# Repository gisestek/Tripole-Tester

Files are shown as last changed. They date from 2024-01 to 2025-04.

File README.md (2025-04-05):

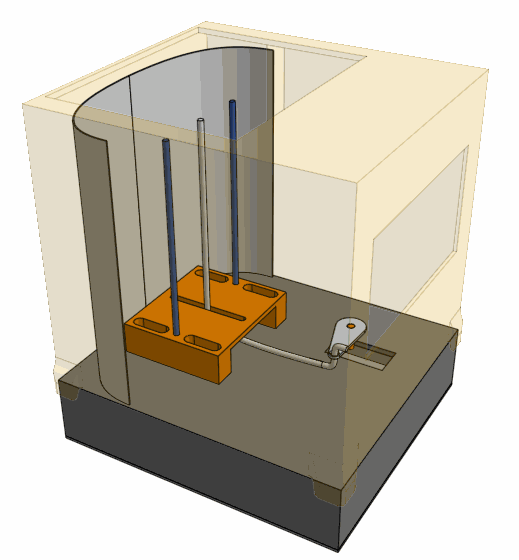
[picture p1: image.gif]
Laite


# Ihmisen syvyysnäön testauslaite

Testi perustuu klassiseen Howard-Dolman -testin periaatteeseen. Laitteessa on kolme pystysuoraa tolppaa (tai sauvaa) rivissä. Koehenkilö katsoo tolppia tietytä etäisyydeltä. Keskimmäistä tolppaa voidaan liikuttaa servo-ohjatusti eteen- tai taaksepäin suhteessa reunimmaisiin tolppiin. Koehenkilön tehtävä on arvioida, onko keskimmäinen tolppa lähempänä vai kauempana kuin reunimmaiset. Etäisyysero reunimmaisiin tolppiin pienenee testin edetessä, ja kun testattava on tehny kolme virhettä, on löydetty stereoerottelykyvyn raja.

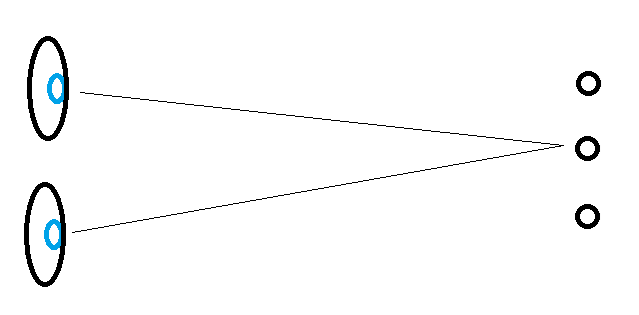
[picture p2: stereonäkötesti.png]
Testin periaatekuva


Testilaite muodostaa WiFI-tukiaseman, johon liitytään kahdella laitteella: 1. Testaajan laite sekä 2. Testattavan pääte.
* Testaajan laitteessa syötetään testihenkilön nimi ja aloitetaan uusi testi, voi seurata testin etenemistä sekä kerätään tulokset. Tulokset voi ladata myös .csv-tiedostona
* Testattavan päätteessä (kännykkä on hyvä) on painikkeet, joilla arvio keskitolpan etäisyydestä tehdään (Lähellä/Kaukana)

## Käyttö:

Kun virrat on päällä, molemmilla laitteilla liitytään WiFiin "Stereovisiontest" (salasana: 12345678)

Testaaja menee selaimella osoitteeseen http://192.168.4.1/admin

Testattava menee selaimella osoitteeseen http://192.168.4.1/

Kansion admin.html ja subject.html ovat emulaattoreita, joilla voi kokeilla interaktiivisesti millaiset GUI:t ovat.

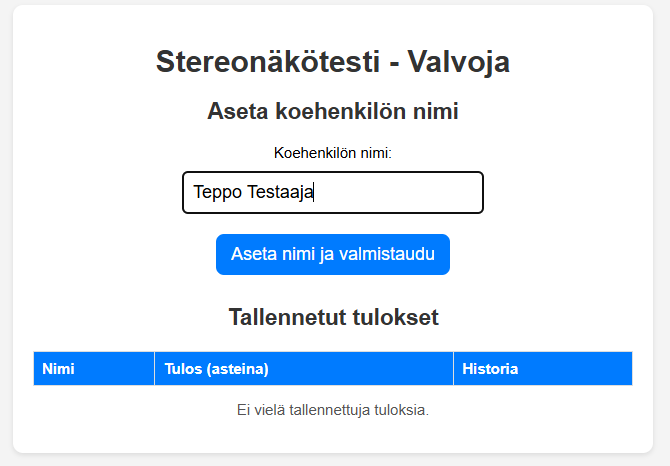
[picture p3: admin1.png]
Admin1

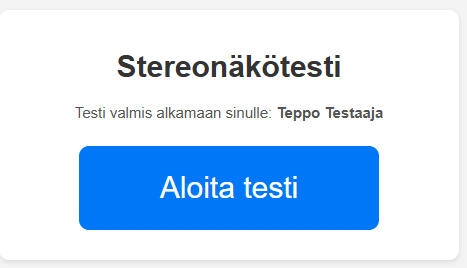
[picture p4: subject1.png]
subject1

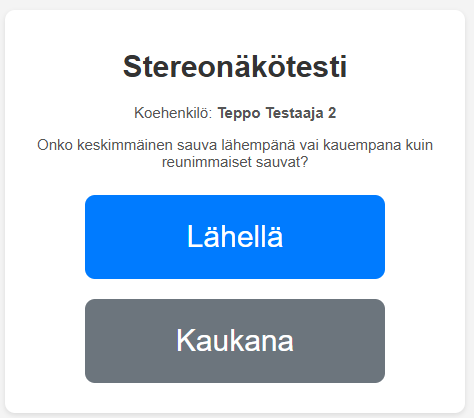
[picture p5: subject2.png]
subject2

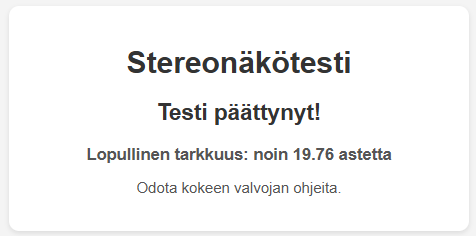
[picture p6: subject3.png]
subject3

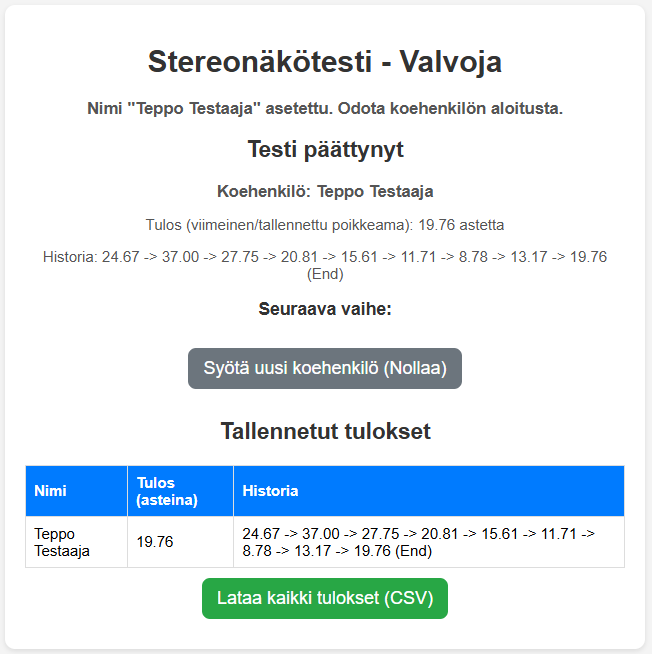
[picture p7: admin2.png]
Admin2


## Laitteisto:

* ESP32
* 9g servo
* Teräslanka (esim TIG-hitsauslankaa)
* 3D-tulostetut osat 
* [Onshape mallit](https://cad.onshape.com/documents/015ba60578bb0acbbb4cbba4/w/e4783b3f15ab7f564ce377d3/e/8b8e0c89aea4ec2eb4cf4481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)

# Stereonäkötestilaitteen katseluetäisyys

Jotta voidaan mitata stereonäön tarkkuutta noin 10 kaarisekunnin tasolle asti:
 
**Laitteiston parametrit:**
* Tolppien välinen sivuttaisetäisyys: n. 10 mm
* Keskimmäisen tolpan liikerata (syvyyssuunnassa): n. 18 mm ( ±9 mm keskikohdasta)

## Laskennan Perusteet

Stereonäön tarkkuus (η) kuvaa pienintä syvyyseroa, jonka henkilö pystyy havaitsemaan kahden eri etäisyydellä olevan kohteen välillä. Se ilmaistaan usein kulmayksiköissä (kaarisekunteina) ja riippuu silmien välisestä etäisyydestä (IPD), kohteiden välisestä fyysisestä syvyyserosta (Δd) ja katseluetäisyydestä (D).

**Kaava:**
Stereotarkkuus radiaaneina approksimoidaan kaavalla:

`η (rad) ≈ (IPD * Δd) / D²`

Missä:
* `η`: Stereotarkkuus radiaaneina
* `IPD`: Silmien välinen etäisyys (Interpupillary distance) metreinä
* `Δd`: Kohteiden välinen syvyysero metreinä
* `D`: Katseluetäisyys metreinä

## Parametrit ja Laskenta

Tavoitteena on laskea etäisyys `D`, jolla laitteen suurin mahdollinen syvyysero `Δd_max` tuottaa juuri 10 kaarisekunnin parallaksieron.

1.  **Tavoiteltu stereotarkkuus (η):**
    * `η = 10 kaarisekuntia`
    * Muunnos radiaaneiksi: `10" = (10 / 3600) * (π / 180) rad ≈ 4.848 * 10⁻⁵ rad`

2.  **Silmien välinen etäisyys (IPD):**
    * Käytetään yleistä keskiarvoa: `IPD ≈ 65 mm = 0.065 m`
    * *Huom: Tämä on oletus, todellinen IPD vaihtelee.*

3.  **Suurin syvyysero (Δd_max):**
    * Laitteen liikerata on 18 mm, joten suurin siirtymä keskikohdasta on puolet siitä.
    * `Δd_max = 18 mm / 2 = 9 mm = 0.009 m`

4.  **Katseluetäisyyden (D) ratkaiseminen:**
    * Muokataan kaavaa: `D² ≈ (IPD * Δd) / η`
    * `D ≈ √[ (IPD * Δd_max) / η ]`
    * Sijoitetaan arvot:
        `D ≈ √[ (0.065 m * 0.009 m) / (4.848 * 10⁻⁵ rad) ]`
        `D ≈ √[ 0.000585 m² / 4.848 * 10⁻⁵ ]`
        `D ≈ √[ 12.067 m² ]`
        `D ≈ 3.47 m`

Tällöin testilaitteen suositeltu katseluetäisyys on noin **3,5 metriä**.

Tällä etäisyydellä laitteen suurin fyysinen syvyyssiirtymä (9 mm) vastaa noin 10 kaarisekunnin stereotarkkuutta (olettaen 65 mm IPD). Tämä mahdollistaa testauksen tavoitellulla tarkkuustasolla laitteen mekaanisten rajoitusten puitteissa. Testiprotokollassa pyritään löytämään pienin havaittava siirtymä, mutta tämä laskettu etäisyys varmistaa, että 10 kaarisekunnin taso on saavutettavissa. Jos teet erikokoisen laitteen, etäisyys on toki eri.

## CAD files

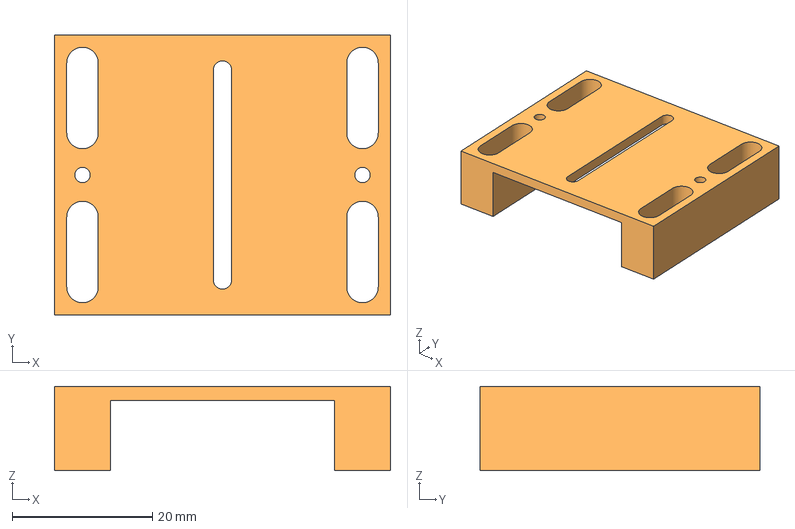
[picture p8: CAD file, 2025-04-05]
3D-mallit/stereonäkömittari - ohjain.3mf
48.0 x 40.0 x 12.0 mm

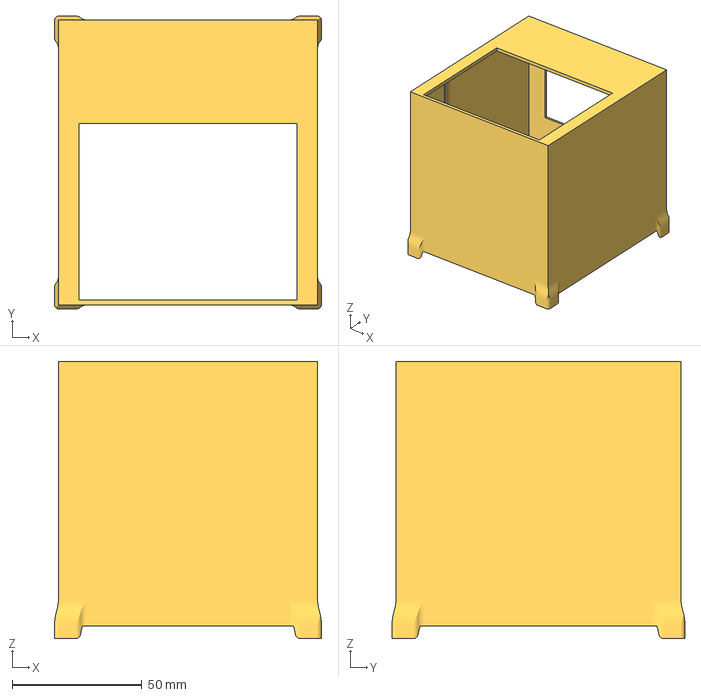
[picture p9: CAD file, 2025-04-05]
3D-mallit/stereonäkömittari - laatikko.3mf
103.0 x 113.0 x 107.0 mm

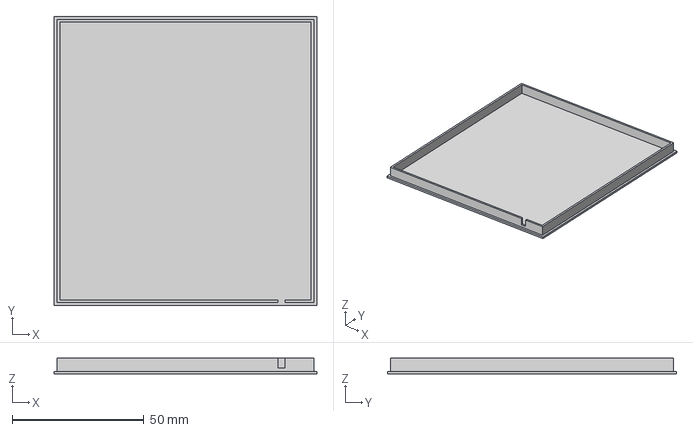
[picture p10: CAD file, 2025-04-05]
3D-mallit/stereonäkömittari - Pohja.3mf
100.0 x 110.0 x 6.00 mm

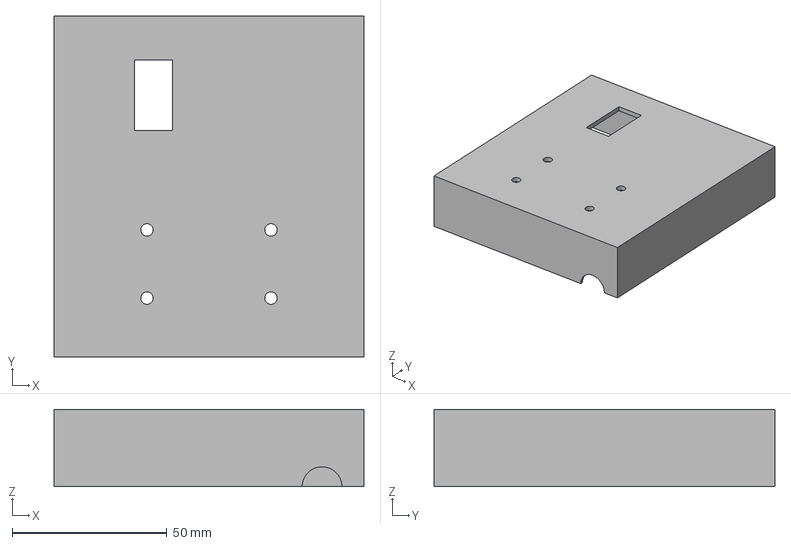
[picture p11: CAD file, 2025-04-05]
3D-mallit/stereonäkömittari - Alusta.3mf
100.0 x 110.0 x 25.0 mm

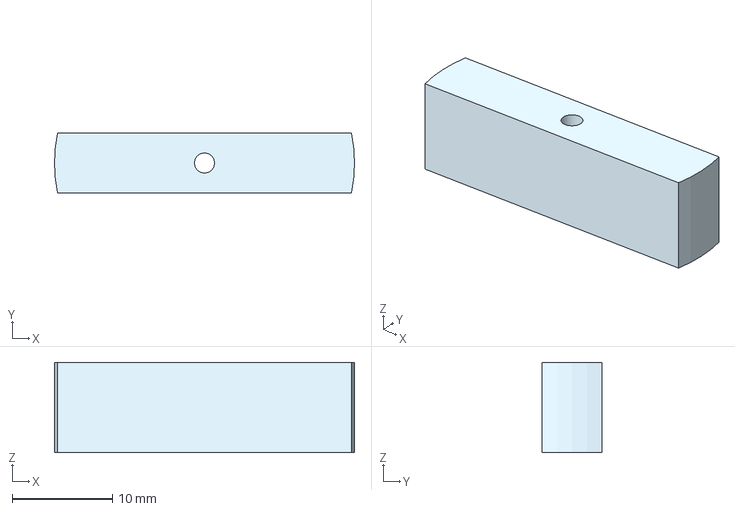
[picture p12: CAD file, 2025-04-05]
3D-mallit/stereonäkömittari - vakain.3mf
30.0 x 6.00 x 9.00 mm

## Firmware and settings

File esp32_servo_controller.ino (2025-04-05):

#include <WiFi.h>
#include <WebServer.h>
#include <ESP32Servo.h>
#include <vector>   // Added for storing results
#include <string>   // Added for string manipulation (optional but good practice)
#include <sstream>  // Added for CSV generation

// WiFi Access Point credentials
const char *ssid = "Stereovisiontest";
const char *password = "12345678"; // Käytä vahvempaa salasanaa tarvittaessa

// Web server on port 80
WebServer server(80);

// Servo setup
Servo servo;
const int servoPin = 13;

// --- Test Variables ---
int centerPosition = 90;  // Servon keskikohta (astetta)
double deflection = 30.0; // Alkupoikkeama (astetta) - Käytetään double tarkkuutta varten
int wrongGuesses = 0;
const int maxWrongGuesses = 3;
bool gameOver = false;
bool gameStarted = false;
int currentPosition; // Servon nykyinen asento (astetta)
const double maxDeflection = 37.0; // Maksimipoikkeama keskikohdasta (astetta)
String deflectionHistory = "";
String currentSubjectName = ""; // Nykyisen koehenkilön nimi

// --- Data Storage ---
struct ResultData {
  String name;
  double finalDeflection;
  String history;
  // Voit lisätä aikaleiman tarvittaessa: unsigned long timestamp;
};
std::vector<ResultData> allResults; // Vektori kaikkien testien tuloksille

// --- HTML & CSS ---
const char* HTML_HEADER = "<!DOCTYPE html><html><head>"
                          "<meta charset='UTF-8'>"
                          "<meta name='viewport' content='width=device-width, initial-scale=1.0'>"
                          "<title>Stereonäkötesti</title>"
                          "<style>"
                          "body { font-family: Arial, sans-serif; text-align: center; margin: 0; padding: 20px; background-color: #f4f4f4; }"
                          "h1, h2, h3 { color: #333; }"
                          "p { color: #555; }"
                          ".container { max-width: 600px; margin: auto; background-color: #fff; padding: 20px; border-radius: 10px; box-shadow: 0 2px 5px rgba(0,0,0,0.1); }"
                          "button, input[type=submit] { font-size: 24px; padding: 15px 20px; margin: 10px 5px; width: calc(80% - 10px); max-width: 300px; border: none; border-radius: 10px; background-color: #007BFF; color: white; cursor: pointer; transition: background-color 0.3s ease; }"
                          "button:hover, input[type=submit]:hover { background-color: #0056b3; }"
                          "button.large-btn { width: calc(90% - 10px); padding: 25px 20px; font-size: 30px; }" // Larger buttons for subject
                          "button.secondary-btn { background-color: #6c757d; }"
                          "button.secondary-btn:hover { background-color: #5a6268; }"
                          "button.download-btn { background-color: #28a745; }"
                          "button.download-btn:hover { background-color: #218838; }"
                          "input[type=text] { font-size: 20px; padding: 10px; margin: 10px 0; width: calc(80% - 22px); max-width: 280px; border: 1px solid #ccc; border-radius: 5px; }"
                          "table { width: 100%; margin-top: 20px; border-collapse: collapse; }"
                          "th, td { border: 1px solid #ddd; padding: 8px; text-align: left; }"
                          "th { background-color: #007BFF; color: white; }"
                          "tr:nth-child(even) { background-color: #f2f2f2; }"
                          ".status { font-weight: bold; margin: 15px 0; font-size: 1.1em; }"
                          ".error { color: red; font-weight: bold; }"
                          "</style></head><body><div class='container'>";

const char* HTML_FOOTER = "</div></body></html>";


// --- Function Declarations ---
void handleRoot();
void handleAdmin();
void handleSetName();
void handleStartGame();
void handleGuess();
void handleDownload();
void resetGame(bool keepName = false);
void setServo();
void setResetMovement();
String getAdminPageContent(String extraMessage = "");
String getSubjectPageContent();
String generateCSV();

// --- Setup ---
void setup() {
    Serial.begin(115200);
    Serial.println("Starting Stereovision Test Server...");

    // Servo setup
    servo.attach(servoPin);
    servo.write(centerPosition); // Aseta servo keskelle alussa
    delay(500); // Pieni viive servon asettumiselle

    // WiFi setup
    WiFi.softAP(ssid, password);
    Serial.print("Access Point SSID: ");
    Serial.println(ssid);
    Serial.print("IP Address: ");
    Serial.println(WiFi.softAPIP());

    // Web server routes
    server.on("/", HTTP_GET, handleRoot);              // Koehenkilön sivu
    server.on("/admin", HTTP_GET, handleAdmin);        // Valvojan sivu
    server.on("/setname", HTTP_POST, handleSetName);   // Nimen asetus (valvoja)
    server.on("/start", HTTP_GET, handleStartGame);    // Testin aloitus (koehenkilö)
    server.on("/guess", HTTP_GET, handleGuess);        // Arvauksen käsittely (koehenkilö)
    server.on("/download", HTTP_GET, handleDownload);  // Tulosten lataus (valvoja)

    server.begin();
    Serial.println("HTTP server started");
    resetGame(true); // Nollaa pelitila, mutta ei välttämättä nimeä alussa
}

// --- Main Loop ---
void loop() {
    server.handleClient();
}

// --- Game Logic ---

// Nollaa testin tila
void resetGame(bool keepName /*= false*/) {
    Serial.println("Resetting game state...");
    deflection = 30.0; // Palauta alkupoikkeama
    wrongGuesses = 0;
    gameOver = false;
    gameStarted = false;
    deflectionHistory = "";
    if (!keepName) {
        currentSubjectName = ""; // Nollaa nimi vain jos keepName on false
        Serial.println("Current subject name cleared.");
    }
    servo.write(centerPosition); // Servo keskelle
    Serial.println("Game reset complete.");
}

// Aloittaa testin (kun koehenkilö painaa Aloita)
void handleStartGame() {
    if (currentSubjectName == "") {
        // Estä aloitus jos nimeä ei ole asetettu
        server.send(200, "text/html", String(HTML_HEADER) + "<h1>Odota</h1><p class='error'>Kokeen valvojan täytyy asettaa nimesi ensin /admin-sivulla.</p>" + HTML_FOOTER);
        return;
    }
    if (!gameStarted) {
        Serial.println("Starting game for: " + currentSubjectName);
        gameStarted = true;
        gameOver = false;
        wrongGuesses = 0;
        deflection = 30.0; // Varmista alkupoikkeama
        deflectionHistory = "";
        setResetMovement(); // Suorita nollausliike
        setServo();         // Aseta ensimmäinen testiasento
        Serial.println("Game started. Initial deflection: " + String(deflection));
    }
    // Ohjaa käyttäjä takaisin pääsivulle (joka näyttää nyt arvauspainikkeet)
    server.sendHeader("Location", "/");
    server.send(303);
}

// Siirtää servon kauas eteen/taakse ennen uutta asentoa
void setResetMovement() {
    int resetPosition = centerPosition + (random(2) ? maxDeflection : -maxDeflection);
    Serial.println("Performing reset movement to: " + String(resetPosition));
    servo.write(resetPosition);
    delay(500); // Anna servon liikkua
    servo.write(centerPosition); // Palaa keskelle hetkeksi (valinnainen, selkeyttää liikettä)
    delay(300);
}

// Siirtää servon uuteen testiasentoon
void setServo() {
    if (gameOver) {
        currentPosition = centerPosition; // Servo keskelle testin päätyttyä
    } else {
        // Randomly choose front or back
        bool goFront = random(2) == 1;
        currentPosition = centerPosition + (goFront ? (int)round(deflection) : -(int)round(deflection));
        // Varmista, ettei mennä yli rajojen (vaikka maxDeflection pitäisi estää tämä)
        currentPosition = constrain(currentPosition, centerPosition - maxDeflection, centerPosition + maxDeflection);
    }
    servo.write(currentPosition);
    Serial.println("Servo moved to: " + String(currentPosition) + " (Deflection: " + String(deflection) + ")");
}

// Käsittelee koehenkilön arvauksen
void handleGuess() {
    if (gameOver || !gameStarted) {
        server.sendHeader("Location", "/");
        server.send(303);
        return;
    }

    String answer = server.arg("answer"); // "front" tai "back"
    bool isFront = currentPosition > centerPosition; // Oliko sauva oikeasti edessä?

    Serial.print("Subject guessed: " + answer + ". Actual position was " + (isFront ? "front" : "back"));

    bool correct = (isFront && answer == "front") || (!isFront && answer == "back");

    if (correct) {
        Serial.println(" -> Correct!");
        deflection *= 0.75; // Pienennä poikkeamaa
        deflection = max(0.5, deflection); // Minimipoikkeama 0.5 astetta
    } else {
        Serial.println(" -> Incorrect!");
        wrongGuesses++;
        deflection *= 1.5; // Suurenna poikkeamaa
        deflection = min(maxDeflection, deflection); // Älä ylitä maksimipoikkeamaa
        Serial.println("Wrong guesses: " + String(wrongGuesses));
        if (wrongGuesses >= maxWrongGuesses) {
            gameOver = true;
            Serial.println("Game Over!");
            // Tallenna tulos
            ResultData result;
            result.name = currentSubjectName;
            result.finalDeflection = deflection; // Tallenna viimeisin (tai ehkä edellinen on parempi?) poikkeama
            result.history = deflectionHistory + String(deflection, 2); // Lisää viimeinen arvo historiaan
            allResults.push_back(result);
            Serial.println("Result saved for " + currentSubjectName + ". Final deflection approx: " + String(deflection));
            setServo(); // Siirrä servo keskelle pelin loputtua
        }
    }

    if (!gameOver) {
        deflectionHistory += String(deflection, 2) + " -> "; // Lisää historiaan (kahden desimaalin tarkkuudella)
        setResetMovement(); // Nollausliike
        setServo();         // Uusi asento
    }

    // Ohjaa takaisin pääsivulle
    server.sendHeader("Location", "/");
    server.send(303);
}


// --- Web Page Handlers ---

// Koehenkilön pääsivu (/)
void handleRoot() {
    server.send(200, "text/html", getSubjectPageContent());
}

// Valvojan sivu (/admin)
void handleAdmin() {
    server.send(200, "text/html", getAdminPageContent());
}

// Käsittelee nimen asettamisen valvojan sivulta
void handleSetName() {
    if (server.hasArg("subjectName")) {
        String newName = server.arg("subjectName");
        newName.trim(); // Poista ylimääräiset välilyönnit

        currentSubjectName = newName; // Aseta nimi (voi olla tyhjäkin, jos halutaan nollata)

        if (newName.length() > 0) {
             Serial.println("Admin set subject name to: " + currentSubjectName);
        } else {
             Serial.println("Admin cleared subject name.");
        }

        resetGame(true); // Nollaa pelitila, mutta pidä (mahdollisesti tyhjä) nimi

        // Ohjaa admin takaisin admin-sivulle näyttämään uusi tila
        server.sendHeader("Location", "/admin");
        server.send(303);
        return;

    } else {
        // Jos subjectName-argumenttia ei jostain syystä tule POST-pyynnössä
        String errorMsg = "<p class='error'>Virhe nimen käsittelyssä!</p>";
        server.send(200, "text/html", getAdminPageContent(errorMsg));
    }
}


// Luo ja lähettää CSV-tiedoston
void handleDownload() {
    Serial.println("Generating CSV file for download...");
    String csvData = generateCSV();
    server.sendHeader("Content-Disposition", "attachment; filename=stereotest_results.csv");
    server.send(200, "text/csv", csvData);
    Serial.println("CSV file sent.");
}

// --- HTML Generation ---

// Luo sisältö koehenkilön sivulle
String getSubjectPageContent() {
    String page = HTML_HEADER;
    page += "<h1>Stereonäkötesti</h1>";

    if (currentSubjectName == "") {
        page += "<p class='status'>Odota, että kokeen valvoja asettaa nimesi järjestelmään /admin-sivulla.</p>";
    } else if (!gameStarted) {
        page += "<p>Testi valmis alkamaan sinulle: <strong>" + currentSubjectName + "</strong></p>";
        page += "<form action='/start' method='get'><button type='submit' class='large-btn'>Aloita testi</button></form>";
    } else if (gameOver) {
        page += "<h2>Testi päättynyt!</h2>";
        // Näytetään viimeisin (pienin saavutettu tai suurin virheellinen) poikkeama
        page += "<p class='status'>Lopullinen tarkkuus: noin " + String(deflection, 2) + " astetta</p>";
        // page += "<p>Historia: " + deflectionHistory + "</p>"; // Voit näyttää historian halutessasi
        page += "<p>Odota kokeen valvojan ohjeita.</p>";
    } else { // Peli käynnissä
        page += "<p>Koehenkilö: <strong>" + currentSubjectName + "</strong></p>";
        page += "<p>Onko keskimmäinen sauva lähempänä vai kauempana kuin reunimmaiset sauvat?</p>";
        // Käytetään formia GET-pyynnön sijaan selkeyden vuoksi, toimii samoin
        page += "<form action='/guess' method='get' style='display: inline-block; width: 100%;'>";
        page += "<input type='hidden' name='answer' value='front'>";
        page += "<button type='submit' class='large-btn'>Lähellä</button>";
        page += "</form><br>";
        page += "<form action='/guess' method='get' style='display: inline-block; width: 100%;'>";
        page += "<input type='hidden' name='answer' value='back'>";
        page += "<button type='submit' class='large-btn secondary-btn'>Kaukana</button>";
        page += "</form>";
        // page += "<p style='font-size: 0.8em; color: #888;'>Poikkeama: " + String(deflection, 2) + "</p>"; // Debug: Näytä poikkeama
    }

    page += HTML_FOOTER;
    return page;
}

// Luo sisältö valvojan sivulle
String getAdminPageContent(String extraMessage /*= ""*/) { // Parametri määritelty täällä
    String page = HTML_HEADER;
    page += "<h1>Stereonäkötesti - Valvoja</h1>";
    page += extraMessage; // Näytä mahdolliset virheet (esim. tyhjä nimi)

    // --- Tilanteen mukaan näytettävä sisältö ---
    if (gameStarted && !gameOver) {
        // Testi käynnissä
        page += "<h2>Testi käynnissä</h2>";
        page += "<p class='status'>Koehenkilö: <strong>" + currentSubjectName + "</strong></p>";
        page += "<p>Nykyinen poikkeama: " + String(deflection, 2) + " astetta</p>";
        page += "<p>Väärät arvaukset: " + String(wrongGuesses) + "/" + String(maxWrongGuesses) + "</p>";
        page += "<p>Historia: " + deflectionHistory + "</p>";
        page += "<p><i>Sivu ei päivity automaattisesti. Päivitä selain nähdäksesi viimeisimmän tilanteen.</i></p>";
        // Voit lisätä "Keskeytä"-napin tänne tarvittaessa
        // page += "<form action='/abort' method='post'><button type='submit' class='secondary-btn'>Keskeytä nykyinen testi</button></form>"; // Vaatisi /abort reitin

    } else if (gameOver) {
        // Testi juuri päättynyt
        page += "<h2>Testi päättynyt</h2>";
        page += "<p class='status'>Koehenkilö: <strong>" + currentSubjectName + "</strong></p>";
        // Hae viimeisin tallennettu tulos (jos löytyy)
        if (!allResults.empty() && allResults.back().name == currentSubjectName) {
             page += "<p>Tulos (pienin/viimeinen poikkeama): " + String(allResults.back().finalDeflection, 2) + " astetta</p>";
             page += "<p>Historia: " + allResults.back().history + "</p>";
        } else {
             page += "<p>Tulos (viimeinen poikkeama): " + String(deflection, 2) + " astetta</p>"; // Näytä nykyinen jos tallennus epäonnistui
             page += "<p class='error'>Huom: Viimeisintä tulosta ei ehkä tallennettu oikein listaan.</p>";
        }

        // Seuraavat toiminnot
        page += "<h3>Seuraava vaihe:</h3>";
         page += "<form action='/setname' method='post'>";
         page += "<input type='hidden' name='subjectName' value=''>"; // Lähetä tyhjä nimi nollataksesi ja palataksesi nimen syöttöön
         page += "<button type='submit' class='secondary-btn'>Syötä uusi koehenkilö (Nollaa)</button>";
         page += "</form>";
         page += "<form action='/download' method='get'><button type='submit' class='download-btn'>Lataa kaikki tulokset (CSV)</button></form>";


    } else if (currentSubjectName != "") {
         // Nimi asetettu, odottaa koehenkilön aloitusta
        page += "<h2>Odotetaan aloitusta</h2>";
        page += "<p class='status'>Testi valmis aloitettavaksi koehenkilölle: <strong>" + currentSubjectName + "</strong></p>";
        page += "<p>Ohjeista koehenkilö yhdistämään laitteen WiFi-verkkoon (" + String(ssid) + ") ja menemään selaimella laitteen IP-osoitteeseen (tai http://" + String(ssid) + ".local, jos mDNS toimii).</p>";
        page += "<p>Koehenkilön näkymä on osoitteessa <a href='/' target='_blank'>/</a>.</p>";
        page += "<p><i>Päivitä tämä sivu nähdäksesi testin etenemisen, kun koehenkilö aloittaa.</i></p>";

         page += "<form action='/setname' method='post'>";
         page += "<input type='hidden' name='subjectName' value=''>"; // Lähetä tyhjä nimi nollataksesi
         page += "<button type='submit' class='secondary-btn'>Vaihda / Nollaa koehenkilö</button>";
         page += "</form>";

    } else {
        // Ei nimeä asetettu, näytä lomake
        page += "<h2>Aseta koehenkilön nimi</h2>";
        page += "<form action='/setname' method='post'>";
        page += "<label for='subjectName'>Koehenkilön nimi:</label><br>";
        page += "<input type='text' id='subjectName' name='subjectName' required><br>";
        page += "<input type='submit' value='Aseta nimi ja valmistaudu'>";
        page += "</form>";
        if (!allResults.empty()) {
             page += "<br><form action='/download' method='get'><button type='submit' class='download-btn'>Lataa tähänastiset tulokset (CSV)</button></form>";
        }
    }


    // --- Näytä kaikkien testien tulokset ---
    if (!allResults.empty()) {
        page += "<h2>Tallennetut tulokset</h2>";
        page += "<table><thead><tr><th>Nimi</th><th>Tulos (asteina)</th><th>Historia</th></tr></thead><tbody>";
        // Käydään tulokset läpi käänteisessä järjestyksessä (uusin ensin)
        for (int i = allResults.size() - 1; i >= 0; i--) {
            page += "<tr>";
            page += "<td>" + allResults[i].name + "</td>";
            page += "<td>" + String(allResults[i].finalDeflection, 2) + "</td>";
            page += "<td>" + allResults[i].history + "</td>";
            page += "</tr>";
        }
        page += "</tbody></table>";
    } else {
         page += "<p>Ei vielä tallennettuja tuloksia.</p>";
    }


    page += HTML_FOOTER;
    return page;
}

// --- CSV Generation ---
String generateCSV() {
    std::stringstream ss;
    // Header row
    ss << "KoehenkiloNimi,LopputulosAsteina,PoikkeamaHistoria\n";

    // Data rows
    for (const auto& result : allResults) { // <- Brace 1 opens
        // Korvataan pilkut ja rivinvaihdot nimestä ja historiasta (varmuuden vuoksi)
        String name = result.name;
        name.replace(",", ";");
        name.replace("\n", " ");
        String history = result.history;
        history.replace(",", ";");
        history.replace("\n", " | ");

        ss << name.c_str() << ","; // Käytä c_str() tai Stringin metodeja
        ss << String(result.finalDeflection, 2).c_str() << ","; // Muunna double stringiksi ja sitten c_str()
        ss << "\"" << history.c_str() << "\"\n"; // Laita historia lainausmerkkeihin, jos se sisältää erikoismerkkejä
    } // <- *** LISÄTTY PUUTTUVA SULKU for-loopille ***

    // Käytä std::string väliaikaisesti, koska ESP String ei välttämättä toimi suoraan stringstreamin kanssa helposti
    std::string std_string = ss.str();
    return String(std_string.c_str());
} // <- *** LISÄTTY PUUTTUVA SULKU funktiolle ***

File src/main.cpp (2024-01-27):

#include <Arduino.h>
#include <Wire.h>
#include <U8glib.h>
#include <AFMotor.h>

// U8glib OLED Display
U8GLIB_SSD1306_128X64 u8g(U8G_I2C_OPT_DEV_0 | U8G_I2C_OPT_FAST);  // Adjust the device number if needed

// Define the stepper motor connections
AF_Stepper motor(200, 1);

// Define the button pins
#define closeButtonPin 2
#define farButtonPin 3

bool testEnded = false;
int targetPosition = 0;
int currentPosition = 0;
int correctResponses = 0;
int consecutiveWrongResponses = 0;
int depthDifference = 100;
const int maxConsecutiveWrongResponses = 3;

// Function to wait for the subject's response with timeout
int waitForResponseWithTimeout() {
  unsigned long startTime = millis();  // Record the start time

  while (millis() - startTime < 10000) {  // Timeout after 10 seconds
    if (digitalRead(closeButtonPin) == LOW) {
      currentPosition = targetPosition - depthDifference / 2;
      // Add code to move the motor to the endstop
      motor.setSpeed(100); // Set the motor speed
      motor.step(-200, FORWARD, SINGLE); // Move the motor to the endstop
      return 1;  // Subject pressed "Close" button
    } else if (digitalRead(farButtonPin) == LOW) {
      currentPosition = targetPosition + depthDifference / 2;
      // Add code to move the motor to the endstop
      motor.setSpeed(100); // Set the motor speed
      motor.step(200, FORWARD, SINGLE); // Move the motor to the endstop
      return 0;  // Subject pressed "Far" button
    }
  }

  // Timeout reached, return a default value (you can adjust as needed)
  return -1;
}

void setup() {
  // Set up OLED display
  u8g.begin();
  u8g.setFont(u8g_font_unifont);  // You can change the font if needed

  // Set up stepper motor
  motor.setSpeed(100);  // Set the speed in rpm

  // Set up buttons
  pinMode(closeButtonPin, INPUT_PULLUP);
  pinMode(farButtonPin, INPUT_PULLUP);

  Serial.begin(9600);
}

void loop() {
  if (!testEnded) {
    // Move the center pole to a random position
    int waitForResponseWithTimeout(); // Declare the waitForResponseWithTimeout() function

    targetPosition = random(500, 1000);  // Larger depth values initially

    int stepsToMove = targetPosition - currentPosition;

    // Display test information on OLED
    u8g.firstPage();
    do {
      u8g.drawStr(0, 10, "Actual: ");
      u8g.drawStr(60, 10, String(currentPosition).c_str());
      u8g.drawStr(0, 25, "Target: ");
      u8g.drawStr(60, 20, String(targetPosition).c_str());
      u8g.drawStr(0, 40, String("Right: " + String(correctResponses)).c_str());
      u8g.drawStr(0, 60, String("Wrong: " + String(consecutiveWrongResponses)).c_str());
    } while (u8g.nextPage());

    // Print motor movement to serial monitor
    Serial.print("Moving ");
    Serial.print(abs(stepsToMove));
    Serial.print(" steps ");
    Serial.println((stepsToMove > 0) ? "forward" : "backward");

    // Move the center pole using the stepper motor
    motor.step(abs(stepsToMove), (stepsToMove > 0) ? FORWARD : BACKWARD, SINGLE);

    // Wait for the subject to respond
    int response = waitForResponseWithTimeout();

    // Check the correctness of the response
    if (response == (stepsToMove > 0)) {
      // If correct response, decrease the depth difference
      depthDifference = max(50, depthDifference - 10);
      consecutiveWrongResponses = 0;
    } else {
      consecutiveWrongResponses++;
      if (consecutiveWrongResponses == maxConsecutiveWrongResponses) {
        // If three consecutive wrong responses, stop the test
        Serial.println("Test Stopped. Results:");
        Serial.print("Total Correct Responses: ");
        Serial.println(correctResponses);
        Serial.print("Final Depth Perception: ");
        Serial.println(currentPosition);

        // Display end result on OLED
        u8g.firstPage();
        do {
          u8g.drawStr(0, 30, "Test Ended");
          u8g.drawStr(0, 50, "Correct: ");
          u8g.drawStr(70, 50, String(correctResponses).c_str());
          u8g.drawStr(0, 60, "Wrong: ");
          u8g.drawStr(70, 60, String(consecutiveWrongResponses).c_str());
        } while (u8g.nextPage());

        testEnded = true;
      }
    }

    // Update correct responses and move to the next iteration
    correctResponses++;

    delay(2000);  // Wait before the next iteration
  } else {
    // Display test has ended on OLED
    u8g.firstPage();
    do {
      u8g.drawStr(0, 30, "Test Ended");
      u8g.drawStr(0, 50, "Correct: ");
      u8g.drawStr(70, 50, String(correctResponses).c_str());
      u8g.drawStr(0, 60, "Wrong: ");
      u8g.drawStr(70, 60, String(consecutiveWrongResponses).c_str());
      u8g.drawStr(0, 80, "Press any button");
      u8g.drawStr(0, 90, "to restart");
    } while (u8g.nextPage());

    // Wait for any button press to reset the test
    if (digitalRead(closeButtonPin) == LOW || digitalRead(farButtonPin) == LOW) {
      testEnded = false;
      correctResponses = 0;
      consecutiveWrongResponses = 0;
      delay(1000);  // Avoid immediate button press recognition
    }
  }
}
